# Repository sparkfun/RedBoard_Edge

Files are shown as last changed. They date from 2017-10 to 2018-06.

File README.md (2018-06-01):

SparkFun RedBoard Edge
========================================

SparkFun RedBoard Edge

[*SparkFun RedBoard Edge (DEV-14525)*](https://www.sparkfun.com/products/14525)

The RedBoard Edge is a RedBoard that's been rebuilt around the idea that projects are eventually put into an enclosure to help clean up their look.

Repository Contents
-------------------

* **/Hardware** - Eagle design files (.brd, .sch)
* **/Production** - Production panel files.

Documentation
--------------
* **[Hookup Guide](https://learn.sparkfun.com/tutorials/redboard-edge-hookup-guide)** - Basic hookup guide for the RedBoard Edge.

Product Versions
----------------
* [DEV-14525](https://www.sparkfun.com/products/14525)- SparkFun red version
* *[SPX-14471 (RETIRED)](https://www.sparkfun.com/products/retired/14471)- SparkX version*

License Information
-------------------

This product is _**open source**_! 

Please review the LICENSE.md file for license information. 

If you have any questions or concerns on licensing, please contact techsupport@sparkfun.com.

Distributed as-is; no warranty is given.

- Your friends at SparkFun.

_<COLLABORATION CREDIT>_

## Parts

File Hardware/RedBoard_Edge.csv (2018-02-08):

Reference | Quantity | Value | Footprint | Datasheet | Field4 | PROD_ID
5V1 5V2 5V3 5V4 ADC1 ADC4 GND1 GND2 GND3 GND4 J5 J6 PWM1 SPI1 | 14 | CONN_04 | Connectors:1X04_NO_SILK |  | CONN-09696
C10 C9 | 2 | 10PF | Capacitors:0603 |  | CAP-11812
C11 | 1 | 10NF | Capacitors:0603 |  | CAP-00867
C3 C6 | 2 | 10UF-TANT | Capacitors:EIA3216 |  | CAP-00811
C1 C12 C2 C4 C8 | 5 | 0.1UF | Capacitors:0603 |  | CAP-00810
C5 | 1 | 47UF-35V | Capacitors:PANASONIC_D |  | CAP-08478
C7 | 1 | 1.0UF | Capacitors:0603 |  | CAP-00868
D1 | 1 | SHOTTKY_MBRA140 | Silicon-Standard:SMA-DIODE |  | DIO-08053
D2 | 1 | LED-YELLOW | LED:LED_550_T1-.75_RT_ANG_PCB |  | DIO-13843
D3 | 1 | LED-GREEN | LED:LED_550_T1-.75_RT_ANG_PCB |  | DIO-13847
D4 | 1 | LED-RED | LED:LED_550_T1-.75_RT_ANG_PCB |  | DIO-13844
D5 | 1 | LED-BLUE | LED:LED_550_T1-.75_RT_ANG_PCB |  | DIO-13890
F1 | 1 | PPTC_HALF-AMP | Fuses:1206 |  | RES-08585
FD1 FD2 FD3 FD4 | 4 | FIDUCIAL1X2 | Aesthetics:FIDUCIAL-1X2 |  | XXX-00000
H1 H2 | 2 | STAND-OFF | Hardware:STAND-OFF |  | XXX-00000
J1 | 1 | CONN_025MM | Connectors:SCREWTERMINAL-5MM-2 |  | CONN-10480
J17 | 1 | QWIIC_CONNECTORJS-1MM | Connectors:1X04_1MM_RA |  | CONN-13694
J2 | 1 | CONN_03X22X3_SILK_MALE_PTH | 2X3 |  | CONN-09701
J20 | 1 | POWER_JACKSMD | Connectors:POWER_JACK_SMD_GND |  | CONN-08106
J4 | 1 | USB_MICRO-B | Connectors:USB-B-MICRO-SMD |  | CONN-11752
JP1 JP2 | 2 | JUMPER | Jumpers:SMT-JUMPER_2_NO_NO-SILK |  |  | XXX-00000
LOGO1 | 1 | SFE_LOGO_NAME_FLAME.1_INCH | Aesthetics:SFE_LOGO_NAME_FLAME_.1 |  | XXX-00000
LOGO2 | 1 | OSHW-LOGOS | Aesthetics:OSHW-LOGO-S |  | XXX-00000
Q1 | 1 | MOSFET-SI2309DS | Silicon-Standard:SOT23-3 |  | TRANS-08285
Q2 Q3 | 2 | BSS138 | Silicon-Standard:SOT23-3 |  | TRANS-00830
R1 R2 R5 R6 | 4 | 470OHM | Resistors:0603 |  | RES-07869
R14 | 1 | 715OHM | Resistors:0603 |  | RES-07850
R15 | 1 | 240OHM | Resistors:0603 |  | RES-07849
R3 R4 | 2 | 10KOHM | Resistors:0603 |  | RES-00824
R10 R7 R8 R9 | 4 | 4.7KOHM | Resistors:0603 |  | RES-07857
S1 | 1 | MOMENTARY-SWITCH-SPST-2-PTH-RT-ANGLE | Switches:TACTILE_SWITCH_PTH_RIGHT_ANGLE_KIT |  | CONN-13896
S2 | 1 | SWITCH_TOGGLE | Switches:TOGGLE_SWITCH-102-C3 |  | PRT-13888
U1 | 1 | CH340GSMD | Silicon-Standard:SO16 |  | IC-13498
U2 | 1 | MIC5205-3.3V | Silicon-Standard:SOT23-5 |  | VREG-00822
U3 U5 | 2 | Standoff_Grounding | Hardware:STANDOFF_GROUNDING
U4 | 1 | ATMEGA328 | Silicon-Standard:TQFP32-08 |  | IC-09069
U6 | 1 | LM1117 | Silicon-Standard:SOT223 |  | VREG-08170
Y1 | 1 | RESONATOR-16MHZ | Clocks:RESONATOR-SMD-3.2X1.3 |  | XTAL-08900
Y2 | 1 | CRYSTAL-12MHZ | Clocks:CRYSTAL-SMD-3.2X2.5MM |  | XTAL-13518

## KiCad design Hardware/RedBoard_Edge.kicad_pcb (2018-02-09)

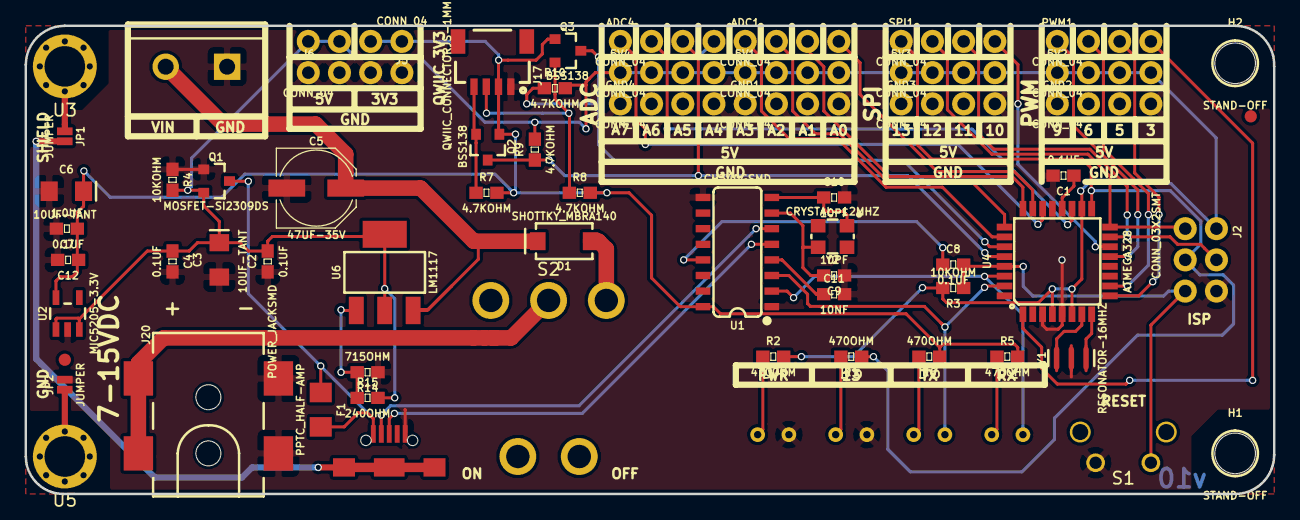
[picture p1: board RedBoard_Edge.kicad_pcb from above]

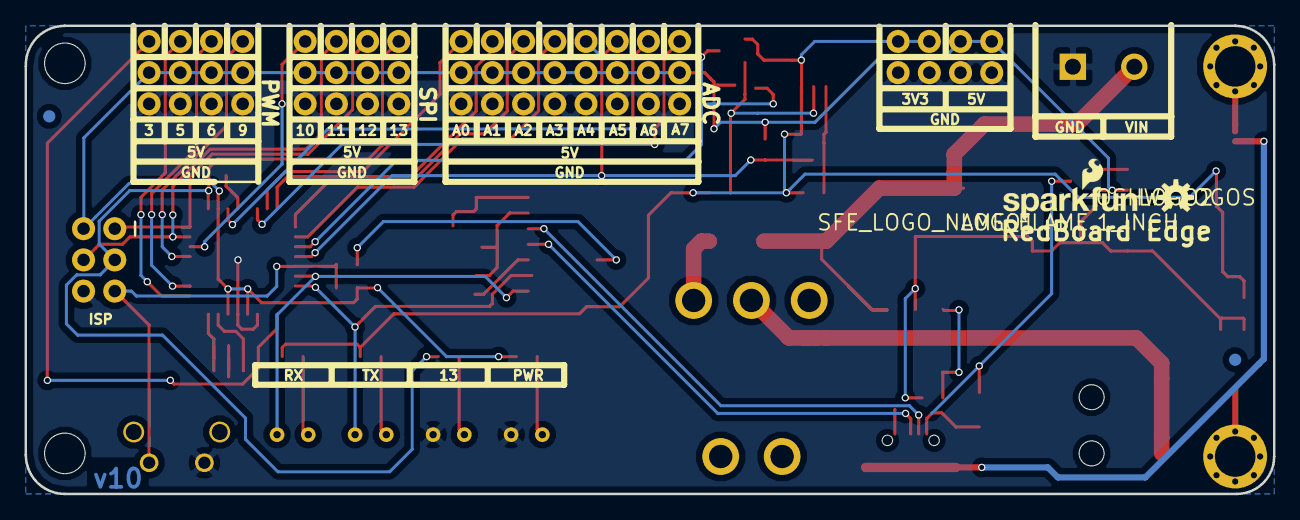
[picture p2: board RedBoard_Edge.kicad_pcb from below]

Board: 2 copper layers, 101.6 x 38.1 mm, 72 parts (4 on the bottom side), 46 nets.

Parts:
5V1, 5V2, 5V3, 5V4: CONN_04; 1X04_NO_SILK
ADC1, ADC4: CONN_04; 1X04_NO_SILK
C1, C2, C4, C8, C12: 0.1UF; 0603
C3, C6: 10UF-TANT; EIA3216
C5: 47UF-35V; PANASONIC_D
C7: 1.0UF; 0603
C9, C10: 10PF; 0603
C11: 10NF; 0603
D1: SHOTTKY_MBRA140; SMA-DIODE
D2: LED-YELLOW; LED_550_T1-.75_RT_ANG_PCB
D3: LED-GREEN; LED_550_T1-.75_RT_ANG_PCB
D4: LED-RED; LED_550_T1-.75_RT_ANG_PCB
D5: LED-BLUE; LED_550_T1-.75_RT_ANG_PCB
F1: PPTC_HALF-AMP; 1206
FD1, FD2, FD3, FD4: FIDUCIAL1X2; FIDUCIAL-1X2
GND1, GND2, GND3, GND4: CONN_04; 1X04_NO_SILK
H1, H2: STAND-OFF
J1: CONN_025MM; SCREWTERMINAL-5MM-2
J2: CONN_03X2SMT; 2X3-NS
J4: USB_MICRO-B; USB-B-MICRO-SMD
J5, J6: CONN_04; 1X04_NO_SILK
J17: QWIIC_CONNECTORJS-1MM; 1X04_1MM_RA
J20: POWER_JACKSMD; POWER_JACK_SMD_GND
JP1, JP2: JUMPER; SMT-JUMPER_2_NO_NO-SILK
LOGO1: SFE_LOGO_NAME_FLAME.1_INCH; SFE_LOGO_NAME_FLAME_.1
LOGO2: OSHW-LOGOS; OSHW-LOGO-S
PWM1: CONN_04; 1X04_NO_SILK
Q1: MOSFET-SI2309DS; SOT23-3
Q2, Q3: BSS138; SOT23-3
R1, R2, R5, R6: 470OHM; 0603
R3, R4: 10KOHM; 0603
R7, R8, R9, R10: 4.7KOHM; 0603
R14: 715OHM; 0603
R15: 240OHM; 0603
S1: MOMENTARY-SWITCH; SWITCH TACTILE SPST-NO 0.05A 12V
S2: SWITCH_TOGGLE; TOGGLE_SWITCH-102-C3
SPI1: CONN_04; 1X04_NO_SILK
U1: CH340GSMD; SO16
U2: MIC5205-3.3V; SOT23-5
U3, U5: Standoff_Grounding; STANDOFF_GROUNDING
U4: ATMEGA328; TQFP32-08
U6: LM1117; SOT223
Y1: RESONATOR-16MHZ; RESONATOR-SMD-3.2X1.3
Y2: CRYSTAL-12MHZ; CRYSTAL-SMD-3.2X2.5MM

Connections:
3.3V: C6.+, C7.1, C12.1, J5.1, J5.2, J17.2, Q2.1, Q3.1, R5.2, R6.1, R7.2, R8.2, U1.16, U2.5
5V: 5V1.1, 5V1.2, 5V1.3, 5V1.4, 5V2.1, 5V2.2, 5V2.3, 5V2.4, 5V3.1, 5V3.2, 5V3.3, 5V3.4, 5V4.1, 5V4.2, 5V4.3, 5V4.4, C2.2, C3.+, C4.1, J2.2, J5.3, J5.4, Q1.2, R2.2, R3.2, R4.2, R9.2, R10.2, R15.2, U2.1, U2.3, U4.4, U4.6, U4.18, U6.2, U6.4
/AD0: ADC1.4, U4.23
/AD1: ADC1.3, U4.24
/AD2: ADC1.2, U4.25
/AD3: ADC1.1, U4.26
/AD6: ADC4.2, U4.19
/AD7: ADC4.1, U4.22
/AREF: C1.1, U4.20
/DTR: C8.1, U1.13
/HI_SCL: ADC4.3, Q2.3, R9.1, U4.28
/HI_SDA: ADC4.4, Q3.3, R10.1, U4.27
/MISO: J2.1, SPI1.2, U4.16
/MOSI: J2.4, SPI1.3, U4.15
/PWM3: PWM1.4, U4.1
/PWM5: PWM1.3, U4.9
/PWM6: PWM1.2, U4.10
/PWM9: PWM1.1, U4.13
/RESET: C8.2, J2.5, R3.1, S1.2, U4.29
/RXI: D2.1, U1.2, U4.30
/SCK: J2.3, R1.1, SPI1.1, U4.17
/SCL: J17.4, Q2.2, R7.1
/SDA: J17.3, Q3.2, R8.1
/SS: SPI1.4, U4.14
/TXO: D3.1, U1.3, U4.31
/USBVCC: F1.1, Q1.3
/usb_shield: J4.SHIE, JP1.2
GND: C1.2, C2.1, C3.-, C4.2, C5.-, C6.-, C7.2, C9.1, C10.2, C11.2, C12.2, D4.1, D5.1, GND1.1, GND1.2, GND1.3, GND1.4, GND2.1, GND2.2, GND2.3, GND2.4, GND3.1, GND3.2, GND3.3, GND3.4, GND4.1, GND4.2, GND4.3, GND4.4, J1.1, J2.6, J4.GND, J6.1, J6.2, J6.3, J6.4, J17.1, J20.GND, JP2.2, Q1.1, R4.1, R14.1, S1.1, U1.1, U1.9, U2.2, U4.3, U4.5, U4.21, Y1.2
unnamed: C9.2, U1.7, Y2.3
unnamed: C10.1, U1.8, Y2.1
unnamed: C11.1, U1.4
unnamed: D1.A, S2.3
unnamed: D2.2, R5.1
unnamed: D3.2, R6.2
unnamed: D4.2, R2.1
unnamed: D5.2, R1.2
unnamed: F1.2, J4.VBUS
unnamed: J4.D+, U1.5
unnamed: J4.D-, U1.6
unnamed: J20.VIN0, S2.2
unnamed: JP1.1, U3.1
unnamed: JP2.1, U5.1
unnamed: R14.2, R15.1, U6.1
unnamed: U4.7, Y1.1
unnamed: U4.8, Y1.3
VIN: C5.+, D1.C, J1.2, U6.3

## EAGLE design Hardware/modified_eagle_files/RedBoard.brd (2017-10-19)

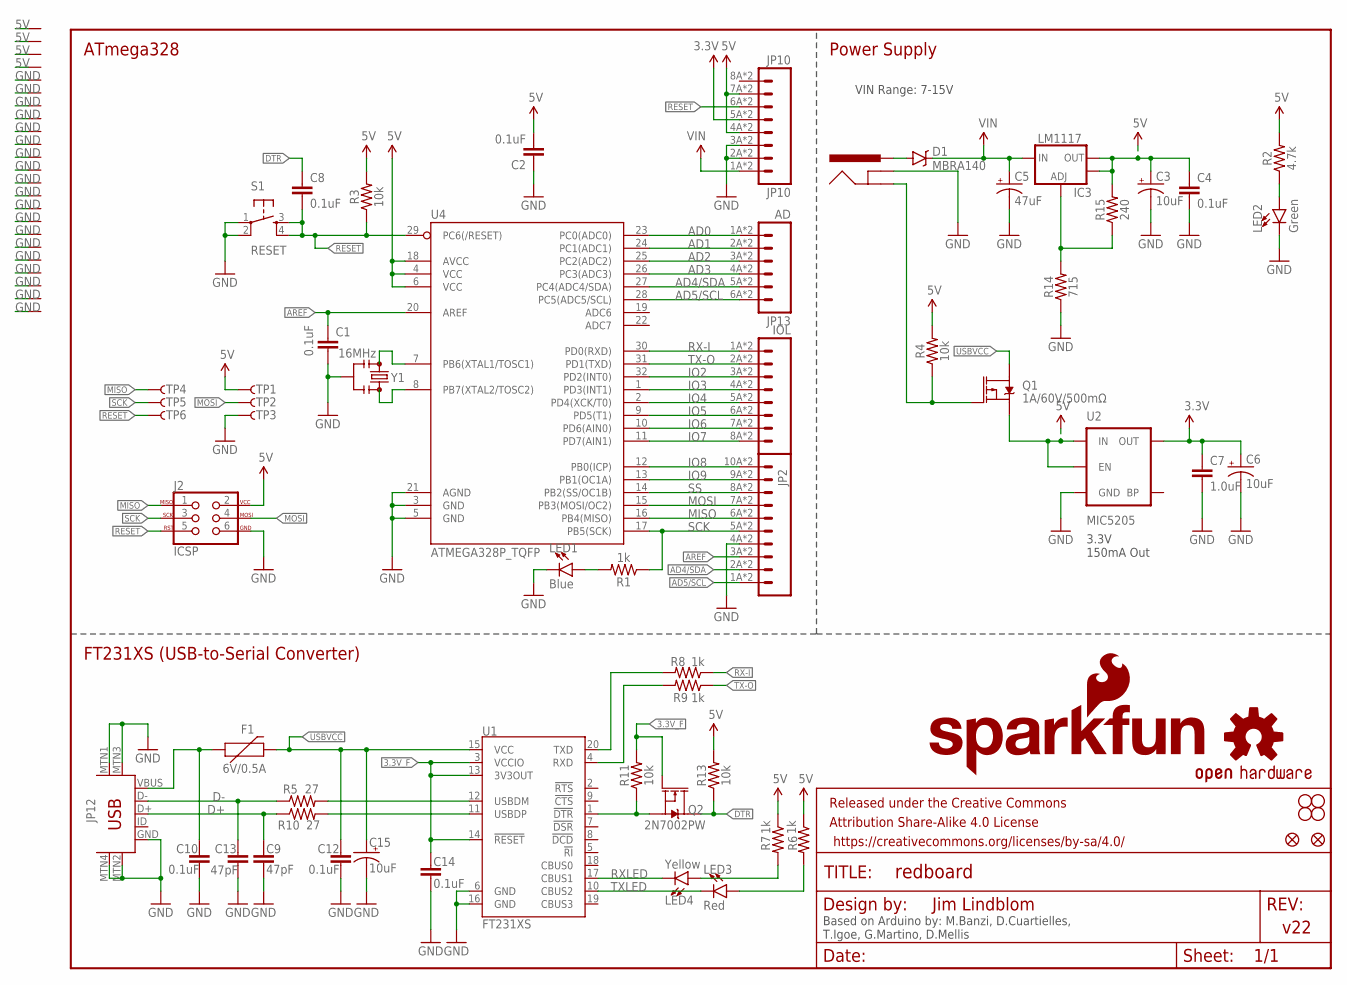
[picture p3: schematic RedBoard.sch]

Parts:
C1, C2, C4, C8, C10, C12, C14: 0.1uF; 0603
C3, C6, C15: 10uF; EIA3216
C5: 47uF; PANASONIC_D
C7: 1.0uF; 0603
C9, C13: 47pF; 0603
D1: MBRA140; SMA-DIODE
F1: 6V/0.5A; 1206
FRAME2: FRAME-LETTER; CREATIVE_COMMONS
IC3: LM1117; SOT223-ALT1
J2: ICSP; 2X3_SMT_POSTS
J3: POWER_JACKSUPER_BOMB_DIGITY; POWER_JACK_SMD_OVERPASTE_SUPER_BOMB_DIGITY
JP1: SFE_LOGO_NAME.1_INCH; SFE_LOGO_NAME_.1
JP2: M10SMD_COMBO; 1X10_SMD_COMBINED
JP3, JP4, JP5, JP6: STAND-OFF
JP7: SFE_LOGO_FLAME.1_INCH; SFE_LOGO_FLAME_.1
JP8, JP9: FIDUCIAL1X2; FIDUCIAL-1X2
JP10: JP10; 1X08_SMD_COMBINED
JP11: IOL; 1X08_SMD_COMBINED
JP12: USB-MINIB-5PIN; USB-MINIB
JP13: AD; 1X06_SMD_STRAIGHT_COMBO
LED1: Blue; LED-1206
LED2: Green; LED-1206
LED3: Red; LED-1206
LED4: Yellow; LED-1206
Q1: 1A/60V/500mΩ; SOT23-3
Q2: 2N7002PW; SOT323
R1, R6, R7, R8, R9: 1k; 0603
R2: 4.7k; 0603
R3, R4, R11, R13: 10k; 0603
R5, R10: 27; 0603
R14: 715; 0603
R15: 240; 0603
S1: RESET; TACTILE-SWITCH-SMD
TP1, TP2, TP3, TP4, TP5, TP6: TP-3x5; PAD.03X.05
U1: FT231XS; SSOP20_L
U2: MIC5205; SOT23-5
U4: ATMEGA328P_TQFP; TQFP32-08
U$16: OSHW-LOGOS; OSHW-LOGO-S
VP_0, VP_1, VP_2, VP_3, VP_4, VP_5, VP_6, VP_7, VP_8, VP_9, VP_10, VP_11, VP_12, VP_13, VP_14, VP_15, VP_16, VP_17, VP_18, VP_19, VP_20, VP_21, VP_22: VPDEV0; VPAC0
Y1: 16MHz; RESONATOR-SMD-3.2X1.3

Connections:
3.3V: C6.+, C7.1, JP10.5A (5), JP10.5B (5), U2.5 (OUT)
3.3V_F: C14.1, Q2.1 (G), R11.2, U1.3 (VCCIO), U1.13 (3V3OUT), U1.14 (!RESET)
5V: C2.2, C3.+, C4.1, IC3.2 (OUT), IC3.4 (OUT), J2.2, JP10.4A (4), JP10.4B (4), JP10.7A (7), JP10.7B (7), Q1.2 (S), R2.2, R3.2, R4.2, R6.1, R7.1, R13.2, R15.2, TP1.P$1, U2.1 (IN), U2.3 (EN), U4.4 (VCC), U4.6 (VCC), U4.18 (AVCC), VP_0.VP, VP_1.VP, VP_2.VP, VP_3.VP
AD0: JP13.1A (1), JP13.1B (1), U4.23 (PC0(ADC0))
AD1: JP13.2A (2), JP13.2B (2), U4.24 (PC1(ADC1))
AD2: JP13.3A (3), JP13.3B (3), U4.25 (PC2(ADC2))
AD3: JP13.4A (4), JP13.4B (4), U4.26 (PC3(ADC3))
AD4/SDA: JP2.2A (2), JP2.2B (2), JP13.5A (5), JP13.5B (5), U4.27 (PC4(ADC4/SDA))
AD5/SCL: JP2.1A (1), JP2.1B (1), JP13.6A (6), JP13.6B (6), U4.28 (PC5(ADC5/SCL))
AREF: C1.1, JP2.3A (3), JP2.3B (3), U4.20 (AREF)
D+: C9.1, JP12.D+, R10.1
D-: C13.1, JP12.D-, R5.1
DTR: C8.1, Q2.3 (D), R13.1
FTDI_DTR: Q2.2 (S), R11.1, U1.1 (!DTR)
GND: C1.2, C2.1, C3.-, C4.2, C5.-, C6.-, C7.2, C9.2, C10.2, C12.2, C13.2, C14.2, C15.-, J2.6, J3.GND (GNDBREAK), JP2.4A (4), JP2.4B (4), JP10.2A (2), JP10.2B (2), JP10.3A (3), JP10.3B (3), JP12.GND, JP12.MTN1 (MTN2), JP12.MTN2 (MTN3), JP12.MTN3 (MTN1), JP12.MTN4, LED1.C, LED2.C, R14.1, S1.1, S1.2, TP3.P$1, U1.6 (GND), U1.16 (GND), U2.2 (GND), U4.3 (GND), U4.5 (GND), U4.21 (AGND), VP_4.VP, VP_5.VP, VP_6.VP, VP_7.VP, VP_8.VP, VP_9.VP, VP_10.VP, VP_11.VP, VP_12.VP, VP_13.VP, VP_14.VP, VP_15.VP, VP_16.VP, VP_17.VP, VP_18.VP, VP_19.VP, VP_20.VP, VP_21.VP, VP_22.VP, Y1.2
INSERT: J3.P$4 (GND), Q1.1 (G), R4.1
IO2: JP11.3A (3), JP11.3B (3), U4.32 (PD2(INT0))
IO3: JP11.4A (4), JP11.4B (4), U4.1 (PD3(INT1))
IO4: JP11.5A (5), JP11.5B (5), U4.2 (PD4(XCK/T0))
IO5: JP11.6A (6), JP11.6B (6), U4.9 (PD5(T1))
IO6: JP11.7A (7), JP11.7B (7), U4.10 (PD6(AIN0))
IO7: JP11.8A (8), JP11.8B (8), U4.11 (PD7(AIN1))
IO8: JP2.10A (10), JP2.10B (10), U4.12 (PB0(ICP))
IO9: JP2.9A (9), JP2.9B (9), U4.13 (PB1(OC1A))
MISO: J2.1, JP2.6A (6), JP2.6B (6), TP4.P$1, U4.16 (PB4(MISO))
MOSI: J2.4, JP2.7A (7), JP2.7B (7), TP2.P$1, U4.15 (PB3(MOSI/OC2))
unnamed: LED1.A, R1.2
unnamed: LED2.A, R2.1
unnamed: U4.7 (PB6(XTAL1/TOSC1)), Y1.1
unnamed: U4.8 (PB7(XTAL2/TOSC2)), Y1.3
unnamed: R5.2, U1.12 (USBDM)
unnamed: R10.2, U1.11 (USBDP)
unnamed: LED3.A, R6.2
unnamed: LED4.A, R7.2
unnamed: IC3.1 (ADJ), R14.2, R15.1
PWRIN: D1.A, J3.VIN0 (PWR)
RESET: C8.2, J2.5, JP10.6A (6), JP10.6B (6), R3.1, S1.3, S1.4, TP6.P$1, U4.29 (PC6(/RESET))
RX-I: JP11.1A (1), JP11.1B (1), R8.1, U4.30 (PD0(RXD))
RXD: R9.2, U1.4 (RXD)
RXLED: LED4.C, U1.17 (CBUS1)
SCK: J2.3, JP2.5A (5), JP2.5B (5), R1.1, TP5.P$1, U4.17 (PB5(SCK))
SS: JP2.8A (8), JP2.8B (8), U4.14 (PB2(SS/OC1B))
TX-O: JP11.2A (2), JP11.2B (2), R9.1, U4.31 (PD1(TXD))
TXD: R8.2, U1.20 (TXD)
TXLED: LED3.C, U1.10 (CBUS2)
USBVCC: C12.1, C15.+, F1.2, Q1.3 (D), U1.15 (VCC)
VIN: C5.+, D1.C, IC3.3 (IN), JP10.1A (1), JP10.1B (1)
VUSB: C10.1, F1.1, JP12.VBUS

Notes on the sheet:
Power Supply
ATmega328
FT231XS (USB-to-Serial Converter)
Based on Arduino by: M.Banzi, D.Cuartielles, T.Igoe, G.Martino, D.Mellis
3.3V 150mA Out
Jim Lindblom
v22
VIN Range: 7-15V

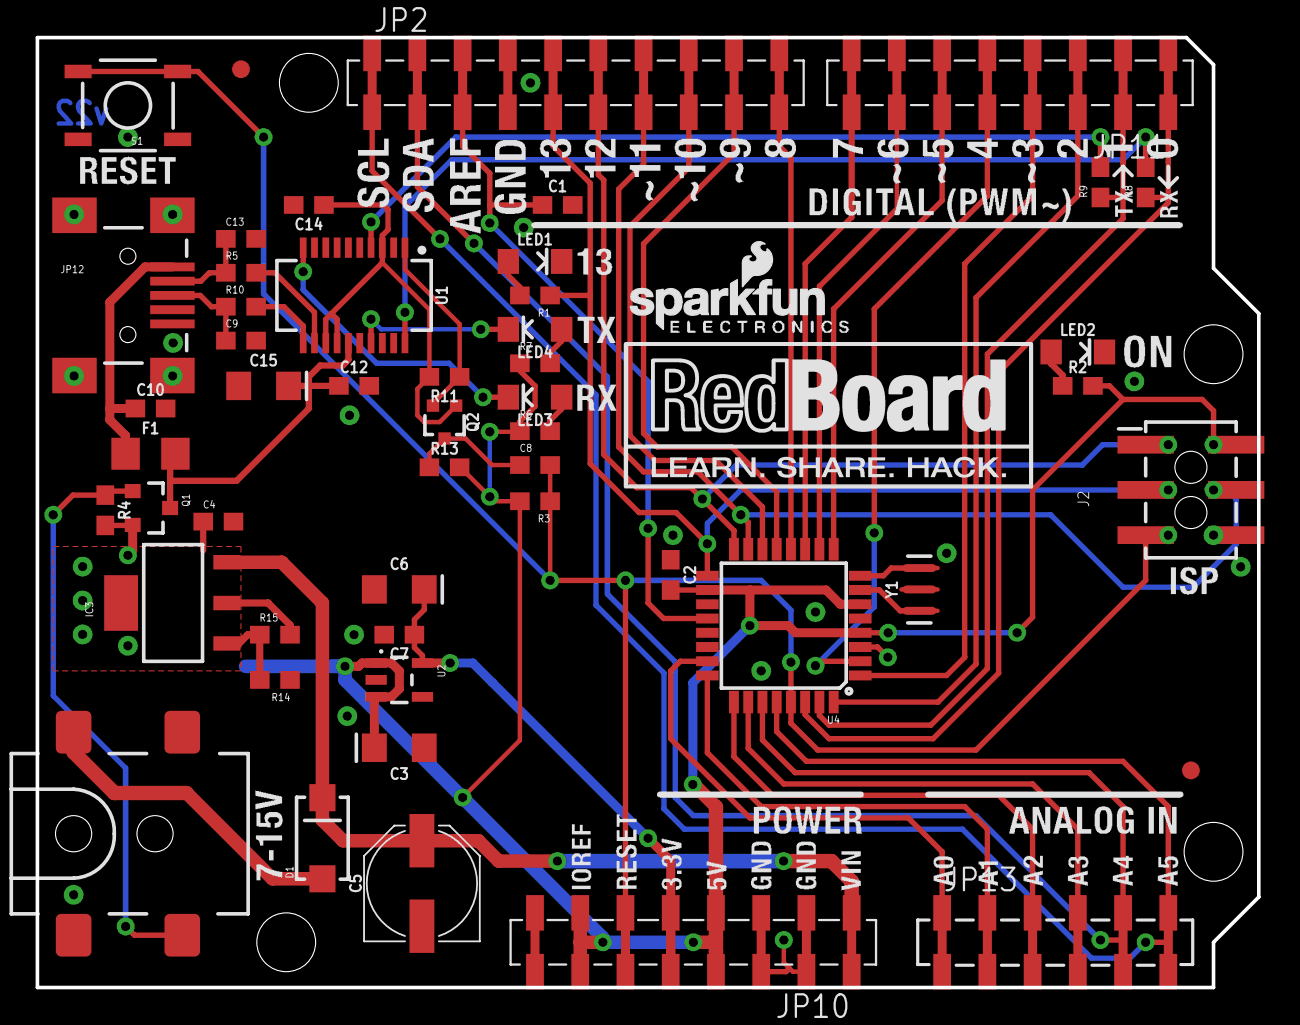
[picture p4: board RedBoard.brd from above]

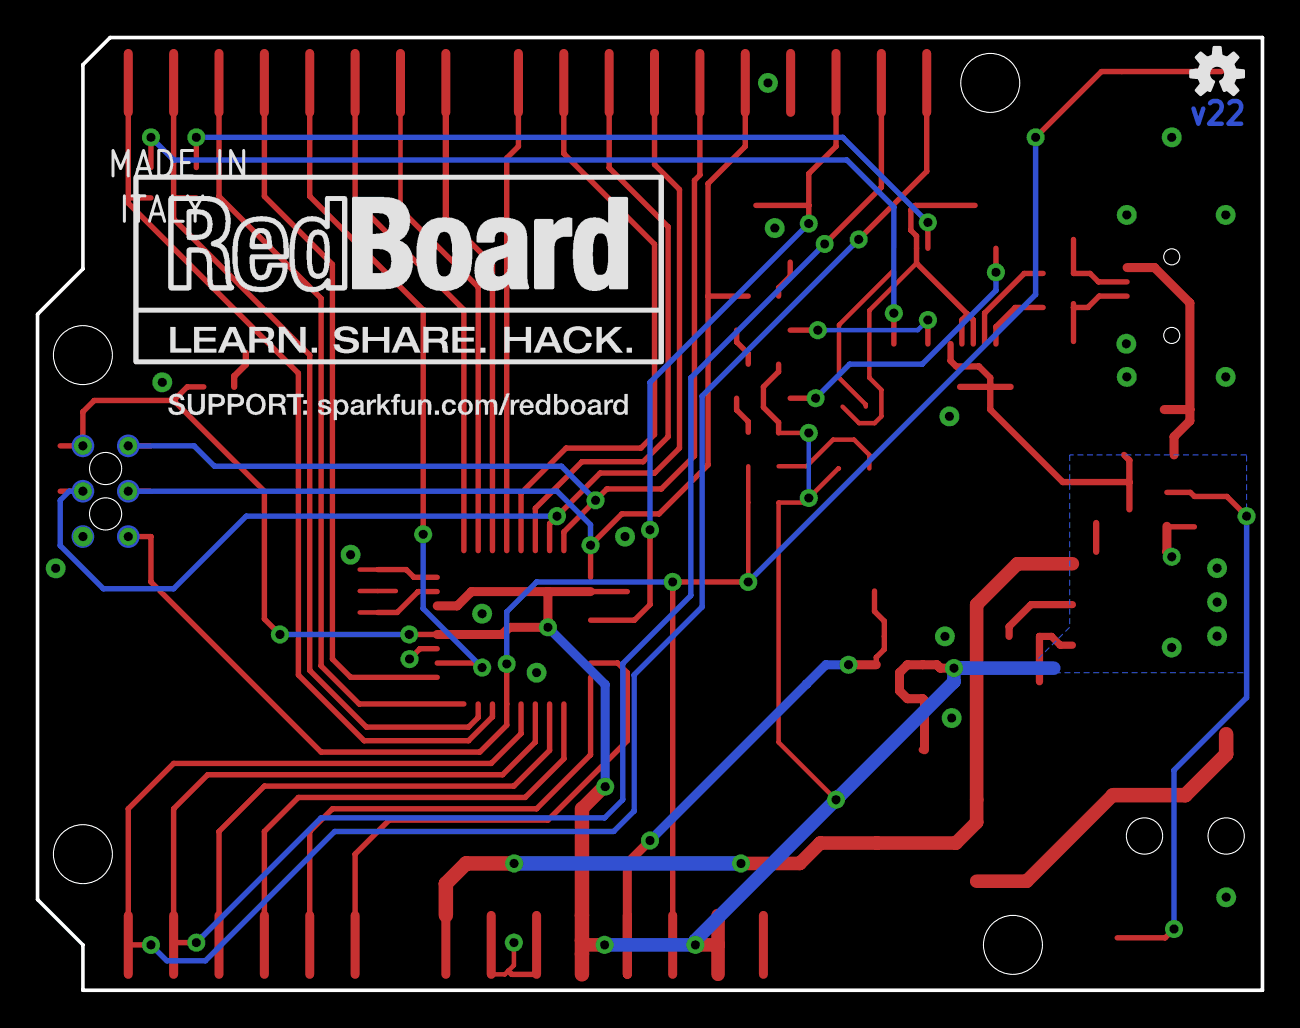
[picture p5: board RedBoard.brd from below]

Board: 2 copper layers, 68.6 x 53.3 mm, 88 parts (7 on the bottom side), 48 nets.

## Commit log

2017-10-26 conversion to Reds, all parts now point to KiCad library in directory C:/Github
    [RedBoard_Edge.csv, RedBoard_Edge.kicad_pcb, RedBoard_Edge.sch]
2017-11-02 Conversion to Reds
    [RedBoard_Edge.kicad_pcb, RedBoard_Edge.sch]
2017-11-03 Post Design review changes
    [RedBoard_Edge.kicad_pcb, RedBoard_Edge.sch]
2017-11-03 Checklist changes
    [Board_Design_Checklist.xls, Board_Design_Checklist_RedBoard Edge_v01.xls, _saved_RedBoard_Edge.sch]
2017-11-03 forgot to save before commit
    [RedBoard_Edge.kicad_pcb, RedBoard_Edge.sch, _saved_RedBoard_Edge.sch]
2017-11-07 QC Double Check Issues
    [RedBoard_Edge.kicad_pcb, RedBoard_Edge.sch]
2017-11-09 Post double double check changes
    [RedBoard_Edge.csv, RedBoard_Edge.sch]
2017-11-14 fixed gerbers
    [RedBoard_Edge-B.Cu.gbl, RedBoard_Edge-B.Mask.gbs, RedBoard_Edge-B.Paste.gbp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]
2017-12-18 updated 12mhz crystal
    [RedBoard_Edge.sch]
2018-01-02 cleaned repo
    [untitled.brd]
2018-01-03 post design review changes, added switch
    [RedBoard_Edge.kicad_pcb, RedBoard_Edge.sch]
2018-01-04 added CC 4.0
    [Board_Design_Checklist_RedBoard Edge_v01.xls, Board_Design_Checklist_Redboard Edge_v02.xls, RedBoard_Edge.csv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]
2018-01-05 Post double check changes
    [RedBoard_Edge.kicad_pcb, RedBoard_Edge.sch]
2018-01-19 updated toggle switch
    [RedBoard_Edge-B.Cu.gbl, RedBoard_Edge-B.Mask.gbs, RedBoard_Edge-B.Paste.gbp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]
2018-02-02 fixed xtal
    [RedBoard_Edge.csv, RedBoard_Edge.kicad_pcb, RedBoard_Edge.sch]
2018-02-07 removed circle
    [RedBoard_Edge.kicad_pcb]
2018-02-08 Fixed broken kicad file
    [RedBoard_Edge.kicad_pcb]
2018-02-09 QC Checklist changes
    [RedBoard_Edge.kicad_pcb, RedBoard_Edge.sch]
2018-05-31 cleaning repo
    [Board_Design_Checklist.xls]
2018-06-01 attampting to remove extra hardware files
    [RedBoard.brd, RedBoard.sch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]
2018-06-01 fixing repo
    [RedBoard.brd, RedBoard.sch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]

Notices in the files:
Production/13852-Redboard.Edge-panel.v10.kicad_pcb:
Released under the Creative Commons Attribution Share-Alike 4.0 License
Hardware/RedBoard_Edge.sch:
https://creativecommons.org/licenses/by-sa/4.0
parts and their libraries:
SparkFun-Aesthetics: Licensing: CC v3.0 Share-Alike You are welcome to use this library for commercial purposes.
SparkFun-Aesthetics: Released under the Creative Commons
